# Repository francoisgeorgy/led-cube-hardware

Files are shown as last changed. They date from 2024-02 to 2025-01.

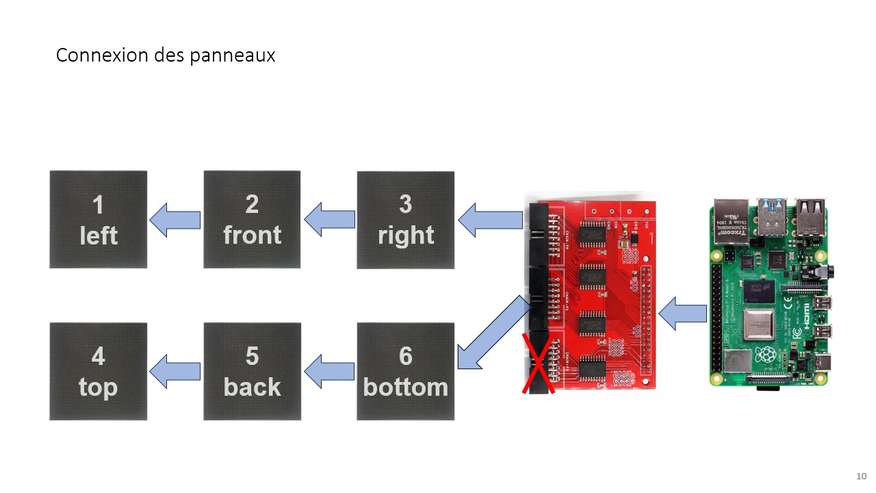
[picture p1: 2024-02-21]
images/panels-connection.jpg

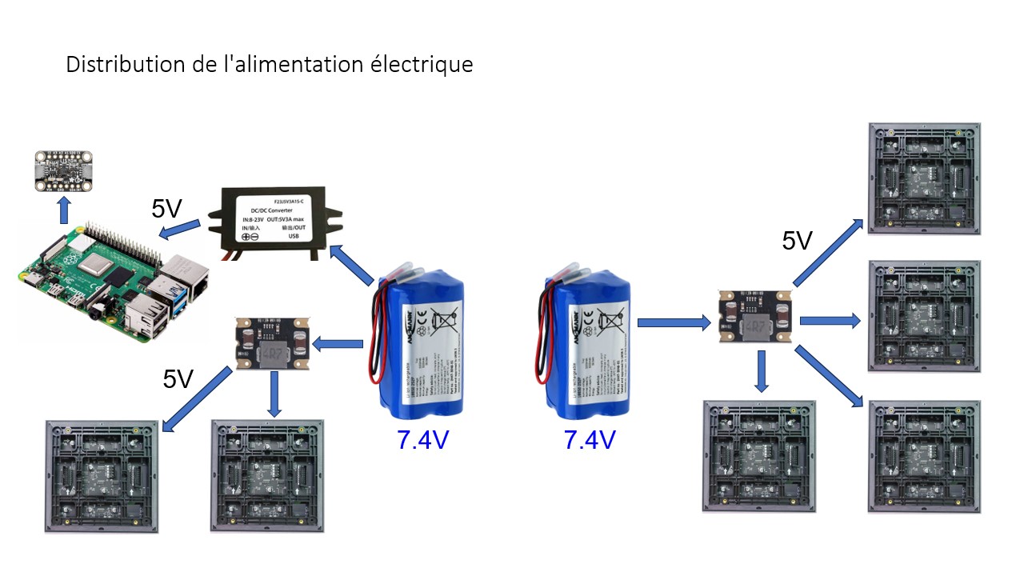
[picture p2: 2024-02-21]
images/power-distribution.jpg

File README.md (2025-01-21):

> [!NOTE]  
> **Project Status: On Hold**
> 
> This project is currently on hold as I’m occupied with other priorities. I still plan to continue working on it and aim to provide updates and complete the documentation before this summer.
> 
> Thank you for your interest and understanding!

LED Cube - Hardware
===================

_To be completed..._

Checkout the [main repository](https://github.com/francoisgeorgy/led-cube) to get more information about the LED Cube.

BOM
---

See [BOM.md](BOM.md).

Brackets and chassis design
---------------------------

> [!WARNING]  
> Please note: all mechanical dimensions are only valid for the LED panels I used. Other panels will most likely have 
> different specifications, particularly regarding the location of the mounting holes. Measure your panels before you 
> begin 3D printing and assembly.

There's an ongoing onShape design available [here](https://cad.onshape.com/documents/eb233c4f247d5269fe5ad74c/w/e5c8d36a0c3e44b3f1d693f6/e/4bf935a9030cdb6dc0eedcf4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).

This design is not final and will evolve. The main change is that the main chassis (which houses the RPi and the batteries)
will no longer be fixed with screws but with magnets. 

Long term goal: 100% screw-free assembly, using magnets only.

3D print
--------

I printed everything with https://jlcpcb.com/

### Corner brackets : 

- STL : [LED-Cube-corner-bracket-v1.stl](3d-print%2FLED-Cube-corner-bracket-v1.stl)
- 3D Technology: MJF
- Material: PA12-HP Nylon
- Colors: -
- Surface Finish: Color :-Dyed Black

### Main chassis : 

- STL : [LED-Cube-base-support.stl](3d-print%2FLED-Cube-base-support.stl)
- 3D Technology: SLS
- Material: 3201PA-F Nylon
- Colors: Black
- Surface Finish: No

This chassis can not be used as-is. You'll have to cut the four corner brackets and fix the chassis with magnets instead of screws. 

I'm designing a new chassis. I will update this page as soon as it is ready.

Panels connections
------------------

See [panels-connection.pdf](panels-connection.pdf) document.

The panels are connected as 2 chains or 3 panels. 

Each chain is connected to the [Hub75 RGB interface](https://www.electrodragon.com/product/rgb-matrix-panel-drive-board-for-raspberry-pi-v2/). The third RGB interface connector is not used. 

Using only 2 of the 3 available Hub75 interface leave some GPIO free to be used for I2C sensors (accelerometer, etc.)

If we had used all 3 Hub75 chains, then there would be no GPIO signal available.

If, however, you wish to use the 3 available Hub75 channels, then there would always be the possibility of using the 
Raspberry Pi's USB ports to communicate with external sensors.

Power distribution
------------------

See [power-distribution.pdf](power-distribution.pdf) and [power-wiring.pdf](power-wiring.pdf) documents.

The mini DC-DC step-down converters are rated at 4A max. That's barely enough to drive 4 panels. One single panel can
draw as much as 4A when displaying white (RGB 255,255,255) at max brightness.

See the [panel datasheet](datasheet%2FCoreman%20LED%20Panel%205407_Indoor-P2.5-32S-64x64-SMD2020-4x45_degree.pdf) for 
more info about the power consumption.

We could use the same mini DC-DC converter for powering the Raspberry Pi. But, for convenience, I used another type 
of DC-DC converter which is directly equipped with a USB-C connector.

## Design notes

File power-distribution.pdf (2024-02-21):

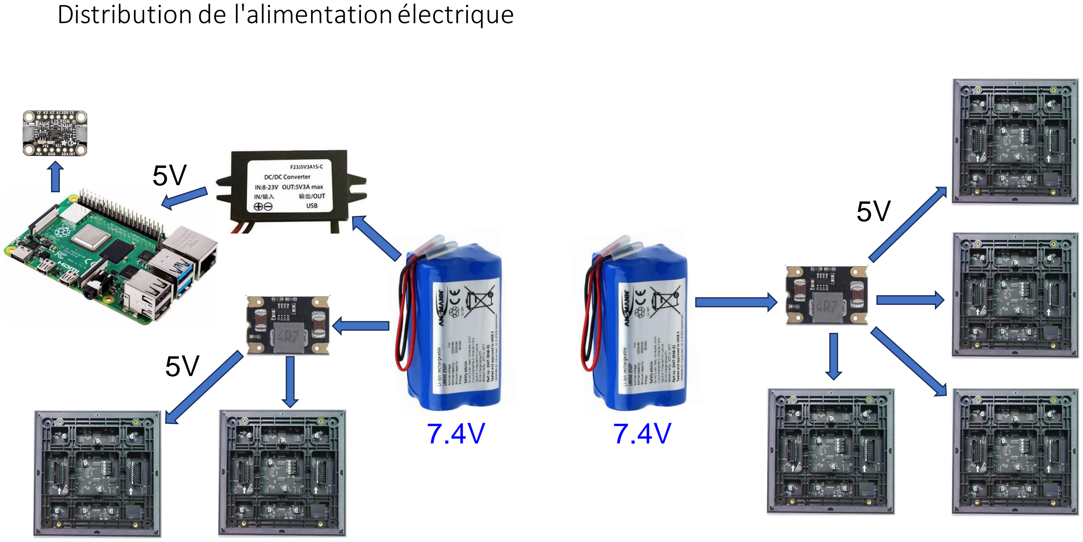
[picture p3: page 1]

7.4V | 7.4V

5V

5V

5V

Distribution de l'alimentation électrique

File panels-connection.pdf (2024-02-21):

10

Connexion des panneaux

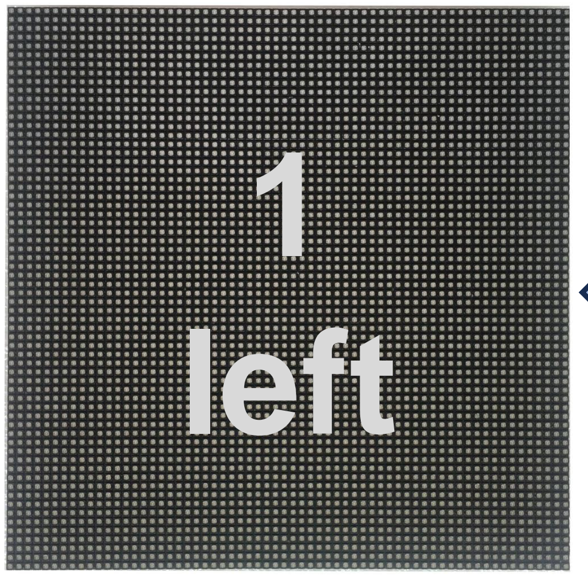
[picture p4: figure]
1 left
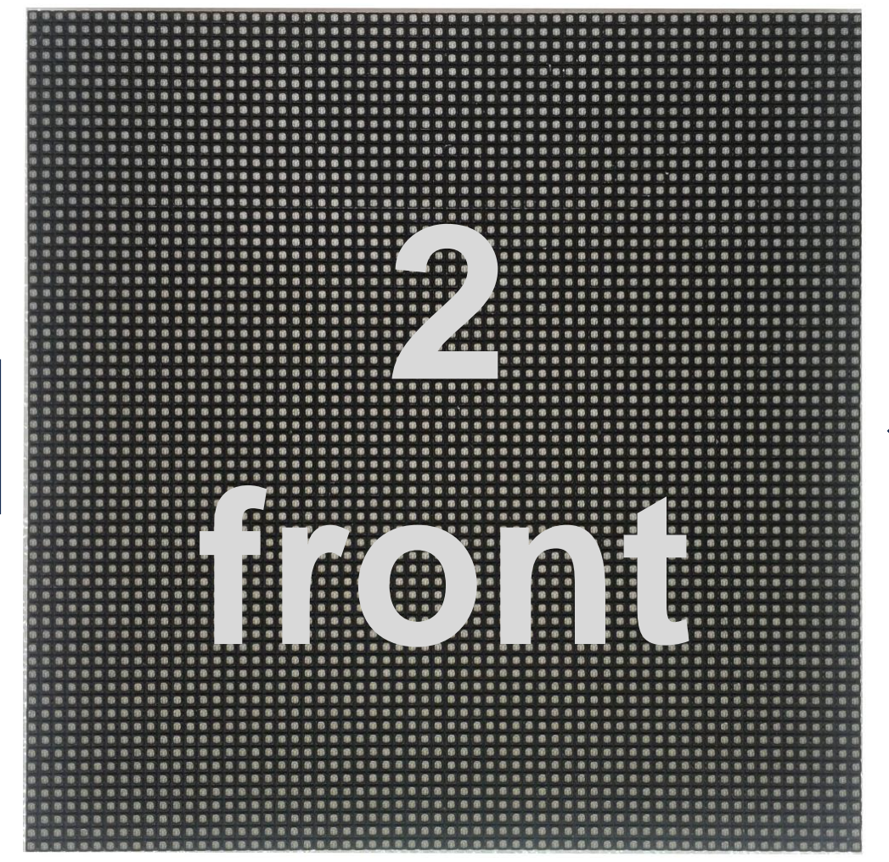
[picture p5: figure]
2 front
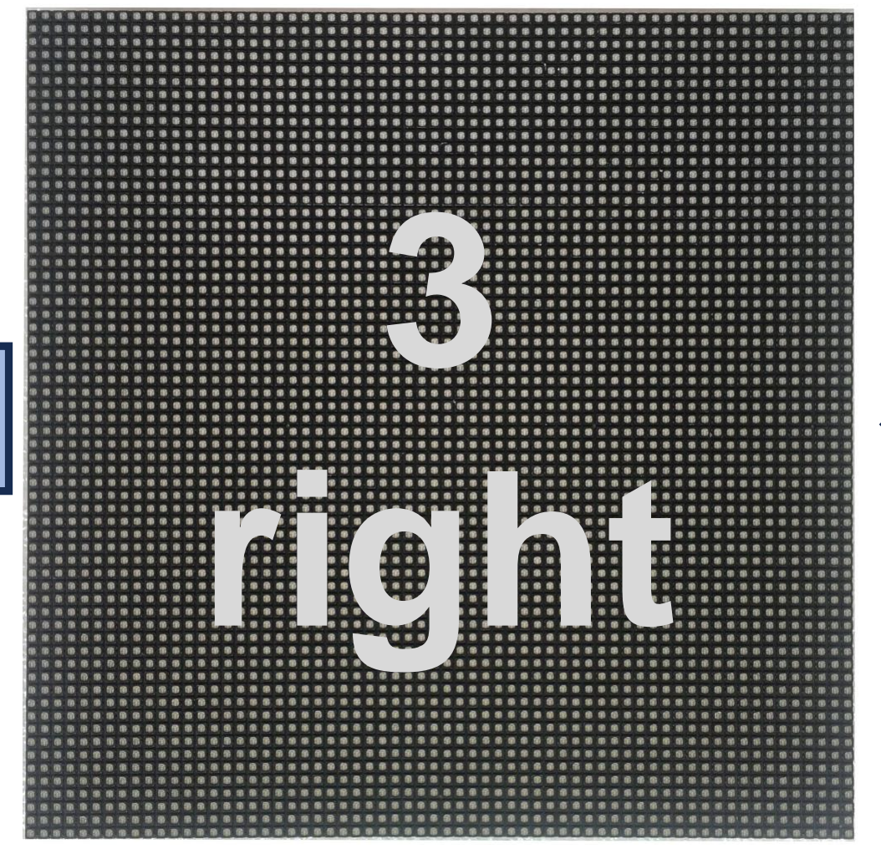
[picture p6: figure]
3 right
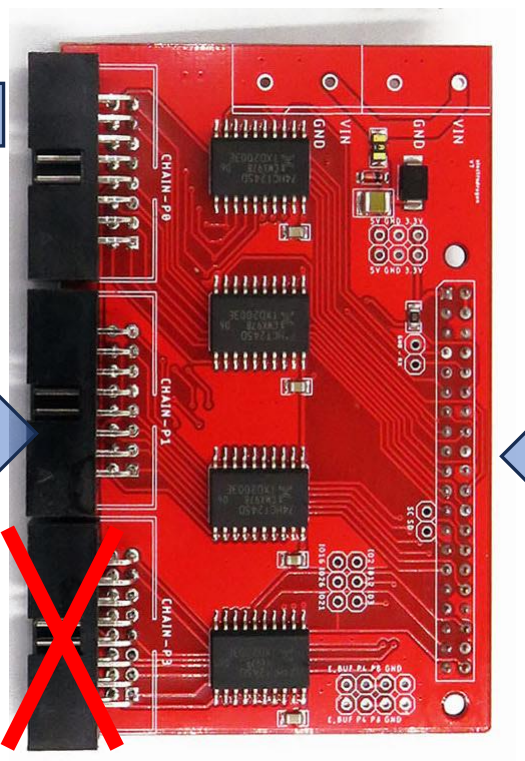
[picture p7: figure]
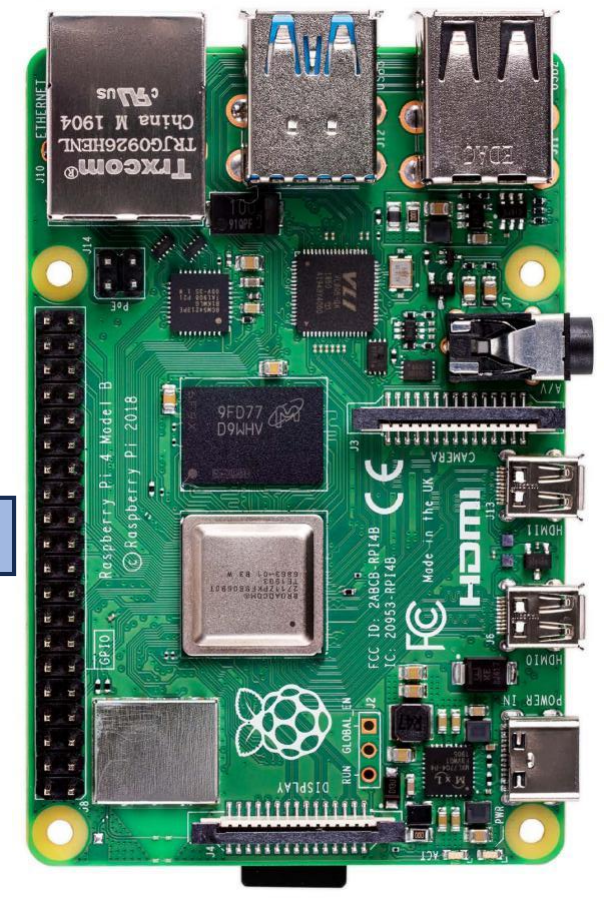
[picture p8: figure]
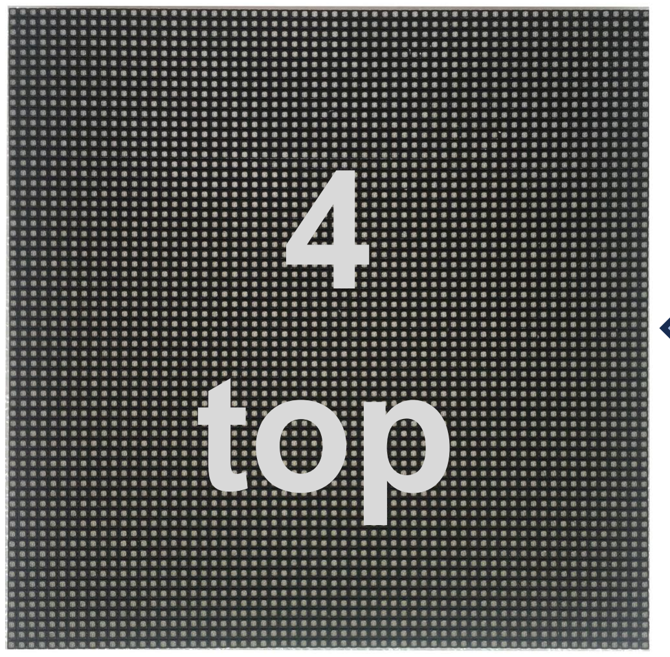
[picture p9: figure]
4 top
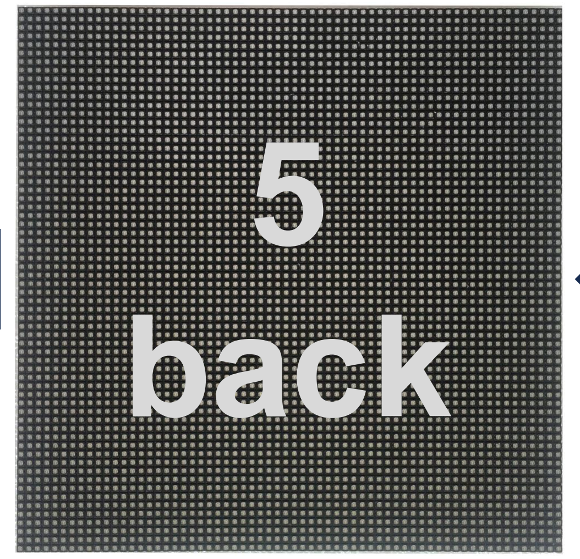
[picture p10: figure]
5 back
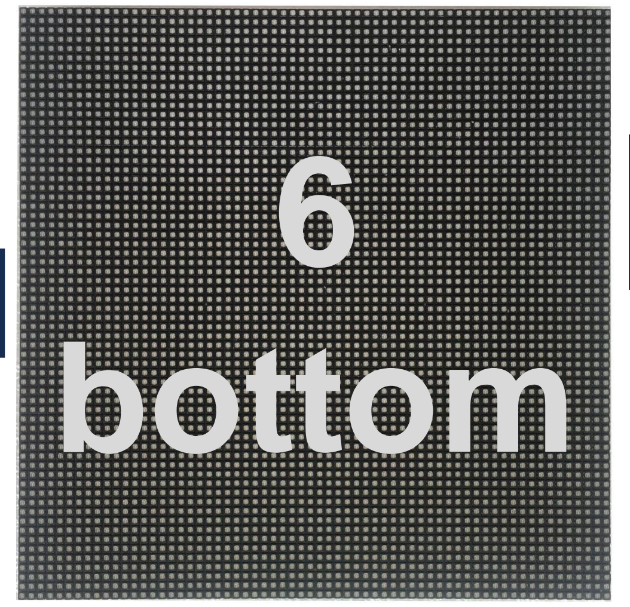
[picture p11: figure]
6 bottom

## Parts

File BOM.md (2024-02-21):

BOM - Bill of materials
=======================

To be completed...

| Pos | Qty | Part | Ref | Vendor | Price |
|-----|----:|---|-----|---|---|
| | 6 | LED module 64x64 P2.5 | | https://www.aliexpress.com/item/1005005288970879.html | |
| | 3 | LED module power cables | | They come with the LED modules. One cable is for two modules. | |
| | 6 | LED module data cables | | They come with the LED modules. | |
| | 1 | Raspberry Pi 4B | | 2GB RAM version is sufficient. | |
| | 1 | RGB Matrix Panel Drive Board For Raspberry Pi V2 | | https://www.electrodragon.com/product/rgb-matrix-panel-drive-board-for-raspberry-pi-v2/ | |
| | 1 | LIS3DH sensor | | https://learn.adafruit.com/adafruit-lis3dh-triple-axis-accelerometer-breakout | |
| | 1 | Cable for LIS3DH sensor | | Recommended length: 20cm | |
| | 2 | DC-DC step-down converter | | https://www.aliexpress.com/item/4001313603033.html | |
| | 1 | DC-DC step-down converter with USB-C output | | https://www.aliexpress.com/item/1005005821935763.html | |
| | 2 | Battery Li-Ion 7.2V 5200mAh | | https://ch.rs-online.com/web/p/akkupacks/8114696 | |
| | 5 | XT30 connectors male | | | |
| | 4 | XT30 connectors female | | | |
| | 1 | XT30 2x female to 1x male adapter | | | |
| | | AWG-18 wire | | About 1m should be enough. | |
| | 3 | WAG0 221 (or equivalent) connectors | | https://www.wago.com/ch-fr/bornes-d-installation/borne-de-raccordement-avec-levier/p/221-415 | |
| |  16 | 10x10x1 mm magnets | | https://www.supermagnete.ch/fre/aimants-bloc-neodyme/parallelepipede-magnetique-10mm-10mm-1.2mm_Q-10-10-1.2-N52N | |
| | 4 | 20x10x2 mm magnets | | https://www.supermagnete.ch/fre/aimants-bloc-neodyme/parallelepipede-magnetique-20mm-10mm-2mm_Q-20-10-02-N | |
| | | Glue for the magnets (UHU Max Repair) | | https://www.uhu.fr/fr/produit.64641 | |
| |  40 | M3x10 screws with low-profile head | | https://www.aliexpress.com/item/1005002106128666.html | |
| | 1 | Li-Ion battery charger | | | |
| | | 16 conductors cable for IDC connectors | | Optional: only if you want to make your own data cables. | |
| | | IDC 16 female connectors | | Optional: only if you want to make your own data cables. | |

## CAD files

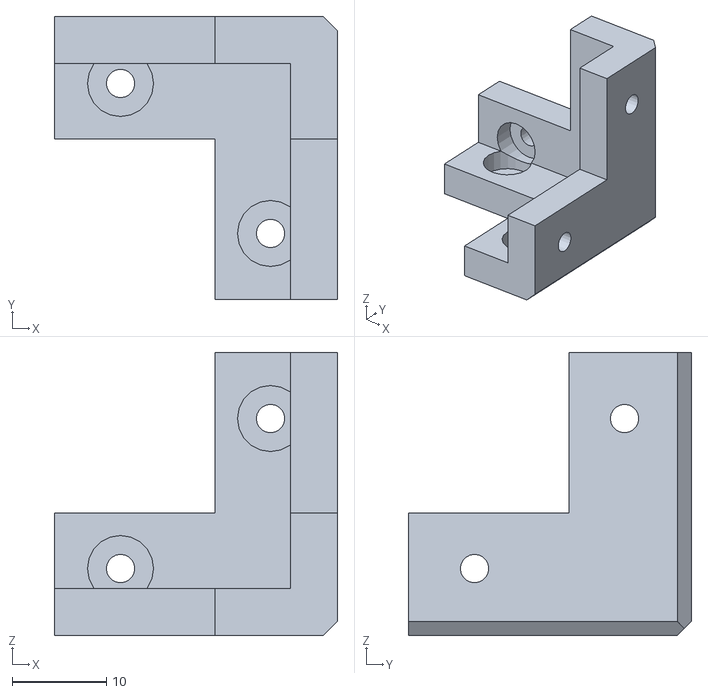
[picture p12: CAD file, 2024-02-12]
3d-print/LED-Cube-corner-bracket-v1.stl
30.0 x 30.0 x 30.0

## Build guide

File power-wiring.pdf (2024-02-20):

LED Cube - Alimentation électrique

Alternative :

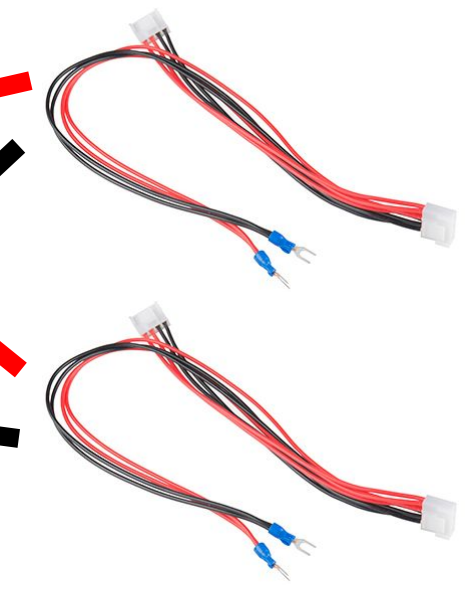
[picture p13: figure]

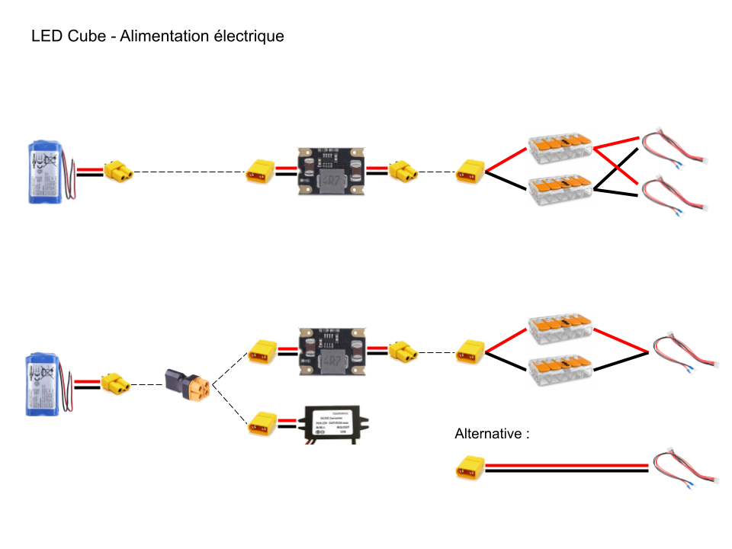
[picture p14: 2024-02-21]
images/power-wiring.png

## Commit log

2024-02-12 BOM, STL
    [LED-Cube-corner-bracket-v1.stl]
2024-02-12 Remarks about the main chassis.
2024-02-12 Power distribution
2024-02-12 LED module datasheet and warning about mechanical dimensions.
2024-02-20 Update BOM; add power wiring schema.
2024-02-21 Update BOM
